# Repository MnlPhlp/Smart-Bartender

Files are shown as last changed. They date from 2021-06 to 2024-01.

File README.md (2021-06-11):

# Smart Bartender
This is a modified version of the [smart-bartender](https://youtu.be/2DopvpNF7J4) from Hacker Shack. It can be controlled via a webpage or an alexa skill.

For the building and electronics part watch the video or check the [hackster.io page](https://www.hackster.io/hackershack/smart-bartender-5c430e) of the original project.

## changes in the build
- switched the peristaltic pump for some cheaper and faster water pumps like [these](https://www.ebay.de/itm/131976810073?var=432870985005)
- using a [neopixel ring](https://www.adafruit.com/product/1463) for lighting
- using a [raspberry pi zero](https://www.raspberrypi.org/products/raspberry-pi-zero/) for control

## setup
To setup your pi you need to first install [circuitpython](https://learn.adafruit.com/circuitpython-on-raspberrypi-linux/installing-circuitpython-on-raspberry-pi). After that run:
```
curl https://raw.githubusercontent.com/MnlPhlp/Smart-Bartender/master/setup.sh | bash
```
This will clone the repository, create a venv and install necessary libraries. 
## start
To run the bartender `cd` into Smart-Bartender and start the program with:
```
sudo python bartender.py
```
> sudo is required for the neopixels to work

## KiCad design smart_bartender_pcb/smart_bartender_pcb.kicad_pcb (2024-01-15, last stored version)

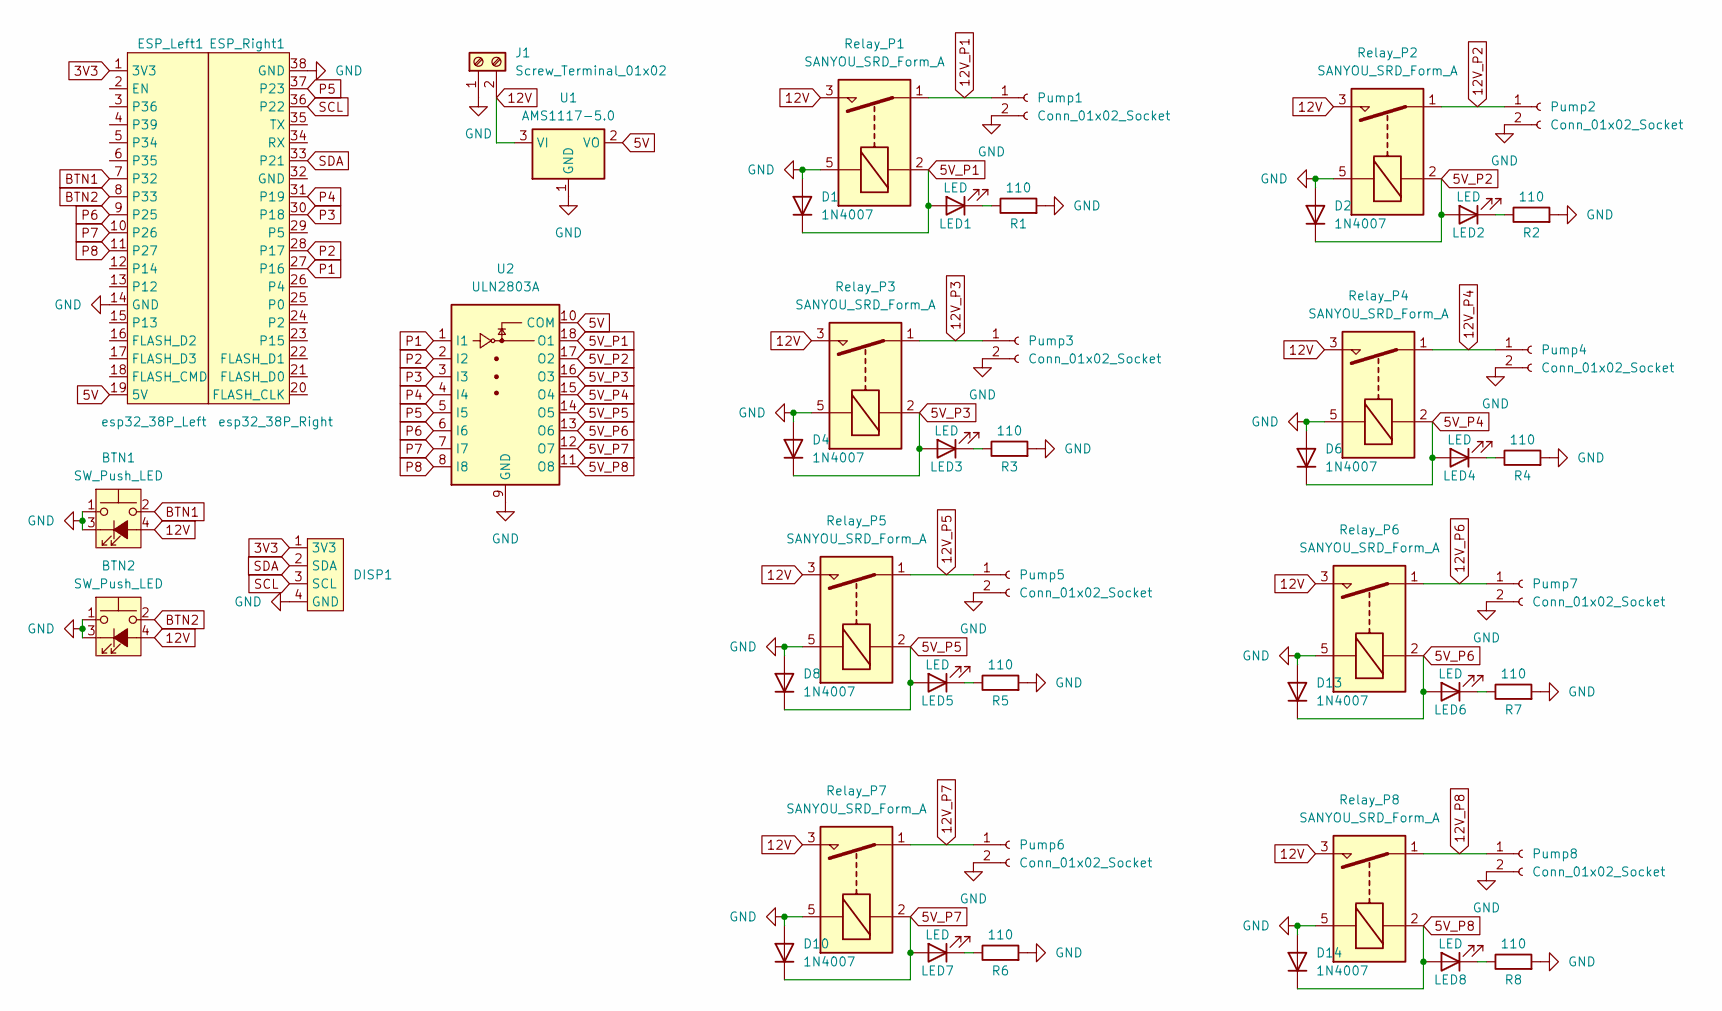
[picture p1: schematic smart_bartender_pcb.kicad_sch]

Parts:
BTN1, BTN2: SW_Push_LED; PinHeader_1x04_P2.54mm_Vertical; LCSC C5116483
D1, D2, D4, D6, D8, D10, D13, D14: 1N4007; D_SOD-123; LCSC C3018540
DISP1: PinSocket_1x04_P2.54mm_Horizontal; LCSC C5333413
ESP_Left1: esp32_38P_Left; esp32_38P_left; LCSC C319202
ESP_Right1: esp32_38P_Right; esp32_38P_right; LCSC C319202
J1: Screw_Terminal_01x02; TerminalBlock_Philmore_TB132_1x02_P5.00mm_Horizontal; LCSC C8385
LED1, LED2, LED3, LED4, LED5, LED6, LED7, LED8: LED; LED_0805_2012Metric; LCSC C2297
Pump1, Pump2, Pump3, Pump4, Pump5, Pump6, Pump7, Pump8: Conn_01x02_Socket; SolderWire-1.5sqmm_1x02_P6mm_D1.7mm_OD3mm_Relief
R1, R2, R3, R4, R5, R6, R7, R8: 110; R_0603_1608Metric; LCSC C22781
Relay_P1, Relay_P2, Relay_P3, Relay_P4, Relay_P5, Relay_P6, Relay_P7, Relay_P8: SANYOU_SRD_Form_A; Relay_SPST_SANYOU_SRD_Series_Form_A; LCSC C688862
U1: AMS1117-5.0; SOT-223-3_TabPin2
U2: ULN2803A; SOP-18_7.495x11.515mm_P1.27mm; LCSC C5252904

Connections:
3V3: DISP1.1 (3V3), ESP_Left1.1 (3V3)
5V: ESP_Left1.19 (5V), U1.2 (VO), U2.10 (COM)
5V_P1: D1.1 (K), LED1.2 (A), Relay_P1.2, U2.18 (O1)
5V_P2: D2.1 (K), LED2.2 (A), Relay_P2.2, U2.17 (O2)
5V_P3: D4.1 (K), LED3.2 (A), Relay_P3.2, U2.16 (O3)
5V_P4: D6.1 (K), LED4.2 (A), Relay_P4.2, U2.15 (O4)
5V_P5: D8.1 (K), LED5.2 (A), Relay_P5.2, U2.14 (O5)
5V_P6: D13.1 (K), LED6.2 (A), Relay_P6.2, U2.13 (O6)
5V_P7: D10.1 (K), LED7.2 (A), Relay_P7.2, U2.12 (O7)
5V_P8: D14.1 (K), LED8.2 (A), Relay_P8.2, U2.11 (O8)
12V: BTN1.4 (A), BTN2.4 (A), J1.2, Relay_P1.3, Relay_P2.3, Relay_P3.3, Relay_P4.3, Relay_P5.3, Relay_P6.3, Relay_P7.3, Relay_P8.3, U1.3 (VI)
12V_P1: Pump1.1, Relay_P1.1
12V_P2: Pump2.1, Relay_P2.1
12V_P3: Pump3.1, Relay_P3.1
12V_P4: Pump4.1, Relay_P4.1
12V_P5: Pump5.1, Relay_P5.1
12V_P6: Pump7.1, Relay_P6.1
12V_P7: Pump6.1, Relay_P7.1
12V_P8: Pump8.1, Relay_P8.1
BTN1: BTN1.2, ESP_Left1.7 (P32)
BTN2: BTN2.2, ESP_Left1.8 (P33)
GND: BTN1.1, BTN1.3 (K), BTN2.1, BTN2.3 (K), D1.2 (A), D2.2 (A), D4.2 (A), D6.2 (A), D8.2 (A), D10.2 (A), D13.2 (A), D14.2 (A), DISP1.4 (GND), ESP_Left1.14 (GND), ESP_Right1.38 (GND), J1.1, Pump1.2, Pump2.2, Pump3.2, Pump4.2, Pump5.2, Pump6.2, Pump7.2, Pump8.2, R1.2, R2.2, R3.2, R4.2, R5.2, R6.2, R7.2, R8.2, Relay_P1.5, Relay_P2.5, Relay_P3.5, Relay_P4.5, Relay_P5.5, Relay_P6.5, Relay_P7.5, Relay_P8.5, U1.1 (GND), U2.9 (GND)
unnamed: LED1.1 (K), R1.1
unnamed: LED2.1 (K), R2.1
unnamed: LED3.1 (K), R3.1
unnamed: LED4.1 (K), R4.1
unnamed: LED5.1 (K), R5.1
unnamed: LED6.1 (K), R7.1
unnamed: LED7.1 (K), R6.1
unnamed: LED8.1 (K), R8.1
P1: ESP_Right1.27 (P16), U2.1 (I1)
P2: ESP_Right1.28 (P17), U2.2 (I2)
P3: ESP_Right1.30 (P18), U2.3 (I3)
P4: ESP_Right1.31 (P19), U2.4 (I4)
P5: ESP_Right1.37 (P23), U2.5 (I5)
P6: ESP_Left1.9 (P25), U2.6 (I6)
P7: ESP_Left1.10 (P26), U2.7 (I7)
P8: ESP_Left1.11 (P27), U2.8 (I8)
SCL: DISP1.3 (SCL), ESP_Right1.36 (P22)
SDA: DISP1.2 (SDA), ESP_Right1.33 (P21)

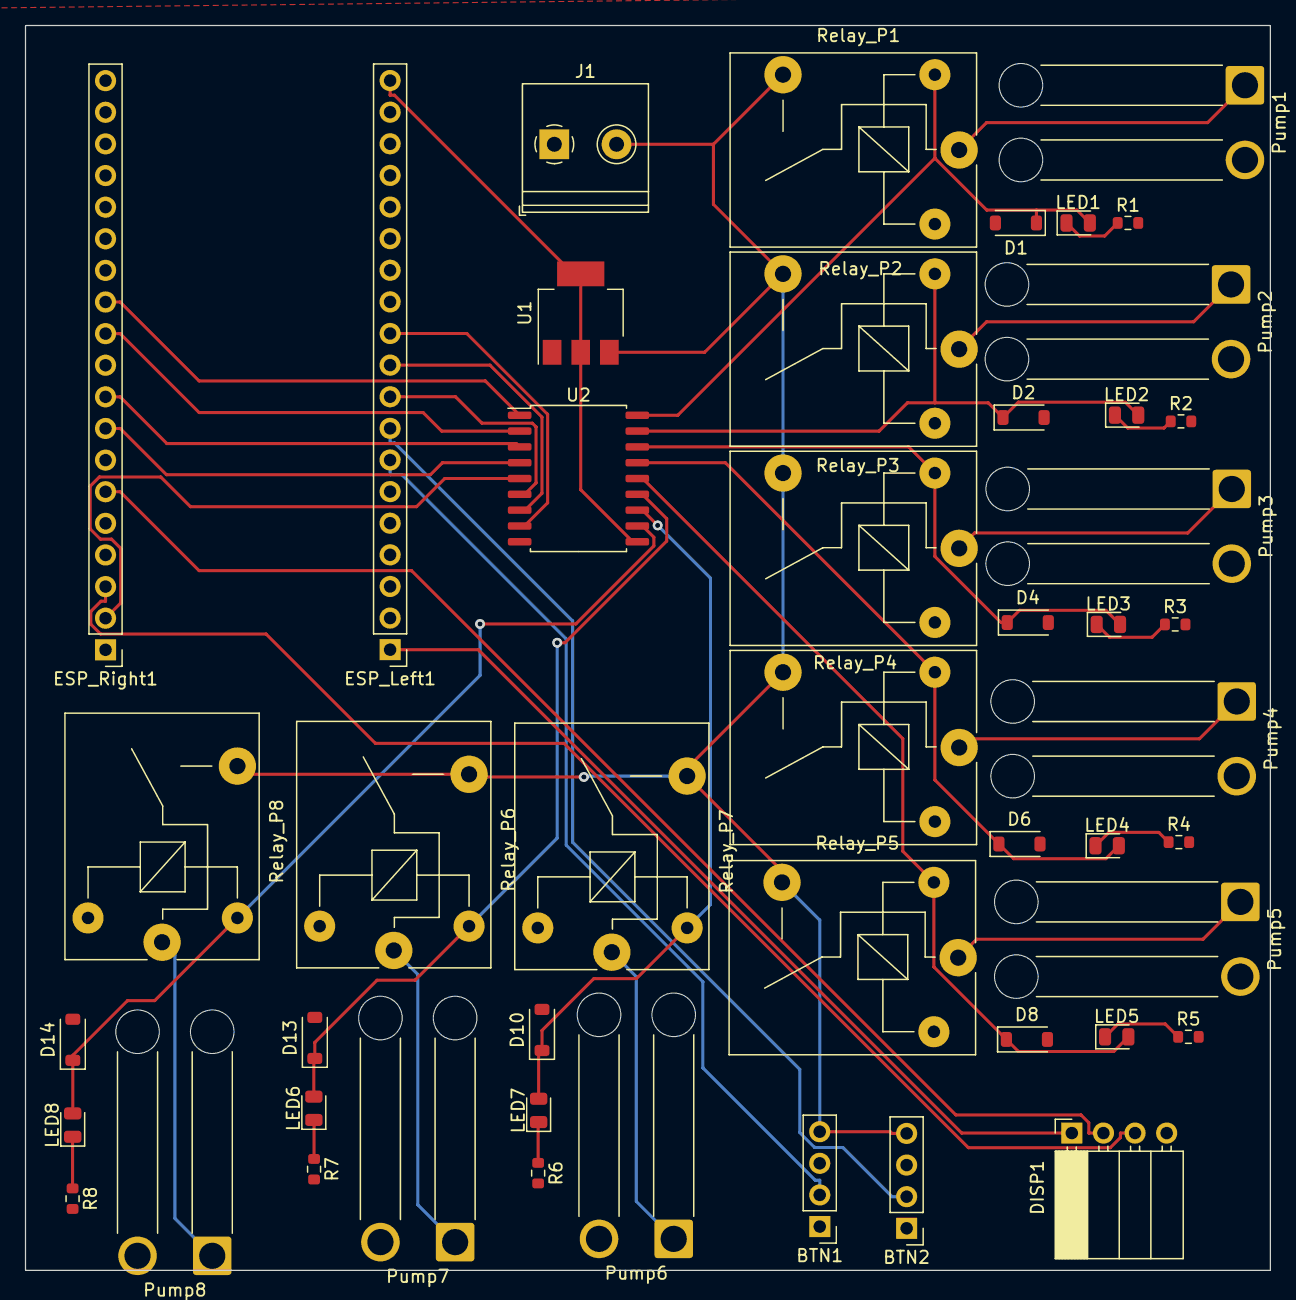
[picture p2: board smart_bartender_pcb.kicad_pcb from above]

Board: 2 copper layers, 100.0 x 100.0 mm, 48 parts (0 on the bottom side), 40 nets.

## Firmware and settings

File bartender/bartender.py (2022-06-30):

from helper.ledHelper import Led
from helper.displayHelper import Display, mockDisplay
from bartenderBase import BartenderBase
import time
import json
import threading
import board
import neopixel
import adafruit_ssd1306
from adafruit_debouncer import Debouncer
import digitalio
from adafruit_blinka.microcontroller.bcm283x.pin import Pin
import logging

SCREEN_WIDTH = 128
SCREEN_HEIGHT = 64

LEFT_BTN_PIN = board.D14
LEFT_PIN_BOUNCE = 500

RIGHT_BTN_PIN = board.D15
RIGHT_PIN_BOUNCE = 500

NUMBER_NEOPIXELS = 12
NEOPIXEL_PIN = board.D18
NEOPIXEL_BRIGHTNESS = 0.5
BASE_COLOR = (50, 0, 0)


class Bartender(BartenderBase):
    leds: Led
    server: BartenderServer
    stats: dict
    running: bool
    stopEvent: threading.Event

    def __init__(self,server, username, password):
        super(Bartender, self).__init__(server,username,password)

        # setup led strip:
        self.leds = Led(neopixel.NeoPixel(
            NEOPIXEL_PIN, NUMBER_NEOPIXELS, brightness=NEOPIXEL_BRIGHTNESS), BASE_COLOR)
        self.leds.clear()
        self.leds.powerUpSequence()
        self.leds.startCycle()

        # setup buttons
        pin1 = digitalio.DigitalInOut(LEFT_BTN_PIN)
        pin1.direction = digitalio.Direction.INPUT
        pin1.pull = digitalio.Pull.UP
        self.btn1 = Debouncer(pin1, interval=0.2)

        pin2 = digitalio.DigitalInOut(RIGHT_BTN_PIN)
        pin2.direction = digitalio.Direction.INPUT
        pin2.pull = digitalio.Pull.UP
        self.btn2 = Debouncer(pin2, interval=0.2)

        # configure screen
        try:
            dsp = adafruit_ssd1306.SSD1306_I2C(
                SCREEN_WIDTH, SCREEN_HEIGHT, board.I2C(), addr=0x3C)
        except:
            logging.warn("no display found. Using mock display")
            dsp = mockDisplay()
        self.display = Display(dsp)
        # Clear display.
        self.display.setup()
        self.display.show()

        # load the pump configuration from file
        self.pump_configuration = Bartender.readPumpConfiguration()

        self.leds.stopCycle()
        self.leds.shutdownSequence()
        logging.info("Done initializing")

    @staticmethod
    def readPumpConfiguration():
        config = json.load(open('config/pump_config.json'))
        for pump in config.keys():
            pinId = config[pump]["pin"]
            pin = digitalio.DigitalInOut(Pin(pinId))
            pin.direction = digitalio.Direction.OUTPUT
            pin.value = True
            config[pump]["pin"] = pin
        return config

    def writePumpConfiguration(self):
        jsonData = {}
        # create a deep copy to change the pins from objects back to ints
        for pump in self.pump_configuration.keys():
            jsonData[pump] = {
                "value": self.pump_configuration[pump]["value"],
                "name": self.pump_configuration[pump]["name"],
                "pin": self.pump_configuration[pump]["pin"]._pin.id,
                "rate": self.pump_configuration[pump]["rate"]

            }
        with open("config/pump_config.json", "w") as jsonFile:
            json.dump(jsonData, jsonFile)

    def clean(self):
        waitTime = 20
        pumpThreads = []

        # cancel any button presses while the drink is being made
        self.running = True

        for pump in self.pump_configuration.keys():
            pump_t = threading.Thread(target=self.pour, args=(
                self.pump_configuration[pump]["pin"], waitTime))
            pumpThreads.append(pump_t)

        # start the pump threads
        for thread in pumpThreads:
            thread.start()

        # start the progress bar
        self.progressBar(waitTime)

        # wait for threads to finish
        for thread in pumpThreads:
            thread.join()

        # show the main menu
        self.menuContext.showMenu()

        # sleep for a couple seconds to make sure the interrupts don't get triggered
        time.sleep(2)

        # reenable interrupts
        self.running = False

    def displayMenuItem(self, menuItem):
        logging.info(f"current menu: {menuItem.name}")
        self.display.clear()
        self.display.displayText(menuItem.name)
        self.display.show()

    def pour(self, pin, waitTime):
        pin.value = False
        logging.info(f"pump on pin {pin._pin} started")
        self.stopEvent.wait(waitTime)
        pin.value = True
        logging.info(f"pump on pin {pin._pin} stoped")

    def progressBar(self, waitTime):
        stepTime = 0.05
        start = time.time()
        percent = 0
        while percent < 100 and not self.stopEvent.is_set():
            loopStart = time.time()
            # update the progress bar
            self.display.drawProgressBar(percent)
            self.display.show()
            # wait the remaining time to limit refreshes
            loopElapsed = time.time()-loopStart
            if loopElapsed < stepTime:
                time.sleep(stepTime-loopElapsed)
            # update the percentage
            percent = ((time.time()-start)/waitTime*100)

        self.display.drawProgressBar(100)

    def makeDrink(self, drink, ingredients):
        # cancel any button presses while the drink is being made
        self.running = True
        self.addStats(drink, ingredients)

        # display the drink in the making
        self.display.clear()
        self.display.displayText(drink)

        # launch a thread to control lighting
        self.leds.startCycle()

        # Parse the drink ingredients and spawn threads for pumps
        maxTime = 0
        pumpThreads = []
        pumps = self.pump_configuration
        for pump in [pumps[key] for key in pumps if pumps[key]["value"] in ingredients]:
            waitTime = ingredients[pump["value"]]/pump["rate"]
            if (waitTime > maxTime):
                maxTime = waitTime
            pump_t = threading.Thread(
                target=self.pour, args=(pump["pin"], waitTime))
            pumpThreads.append(pump_t)

        # start the pump threads
        for thread in pumpThreads:
            thread.start()

        # start the progress bar
        self.progressBar(maxTime)

        # wait for threads to finish
        for thread in pumpThreads:
            thread.join()

        # show the main menu
        self.menuContext.showMenu()

        # stop the light thread
        self.leds.stopCycle()
        self.leds.shutdownSequence()

        # reenable interrupts
        self.running = False

    def handleInput(self):
        self.btn1.update()
        self.btn2.update()
        if self.btn1.fell:
            self.left_btn()
        if self.btn2.fell:
            self.right_btn()

    def stop(self):
        logging.info("stopping current drink")
        self.stopEvent.set()
        # wait for everything to finish
        while self.running:
            time.sleep(0.5)
        self.stopEvent.clear()
        logging.info("drink is stoped")
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

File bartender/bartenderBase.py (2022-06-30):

import string
from menu import MenuItem, Menu, Back, MenuContext, MenuDelegate
import json
from datetime import datetime
import threading
import logging
from time import sleep
from config.drinks import drink_list as drink_list_import, drink_options as drink_options_import
import requests


class BartenderBase(MenuDelegate):
    stats: dict
    running: bool
    stopEvent: threading.Event
    server: string
    username: string
    password: string

    def __init__(self,server, username, password):
        self.running = False
        self.stopEvent = threading.Event()
        self.server = server
        self.username = username
        self.password = password

        self.stats = self.loadStats()

    def addStats(self, drink, ingredients):
        time = datetime.now().strftime("%d.%m.%y-%H:%M")
        # create entries if they don't exist
        if not time in self.stats:
            self.stats[time] = {}
        stats = self.stats[time]
        total = self.stats["total"]
        if not drink in stats:
            stats[drink] = 0
        if not drink in total:
            total[drink] = 0
        # add the volume to the entries
        total[drink] += 1
        stats[drink] = total[drink]
        self.saveStats()

    def loadStats(self):
        try:
            with open("stats.json", "rt") as f:
                return json.load(f)
        except FileNotFoundError:
            return {"total": {}}

    def saveStats(self):
        with open("stats.json", "wt") as f:
            return json.dump(self.stats, f)

    def buildMenu(self, drink_list, drink_options):
        # create a new main menu
        m = Menu("Main Menu")

        # add drink options
        drink_opts = []
        for d in drink_list:
            drink_opts.append(MenuItem('drink', d["name"], {
                              "ingredients": d["ingredients"]}))

        configuration_menu = Menu("Configure")

        # add pump configuration options
        pump_opts = []
        for p in sorted(self.pump_configuration.keys()):
            config = Menu(self.pump_configuration[p]["name"])
            # add fluid options for each pump
            for opt in drink_options:
                # star the selected option
                selected = "*" if opt == self.pump_configuration[p]["value"] else ""
                config.addOption(MenuItem('pump_selection', opt, {
                                 "key": p, "value": opt, "name": opt}))
            # add a back button so the user can return without modifying
            config.addOption(Back("Back"))
            config.setParent(configuration_menu)
            pump_opts.append(config)

        # add pump menus to the configuration menu
        configuration_menu.addOptions(pump_opts)
        # add a back button to the configuration menu
        configuration_menu.addOption(Back("Back"))
        # adds an option that cleans all pumps to the configuration menu
        configuration_menu.addOption(MenuItem('clean', 'Clean'))
        # add reload drinks option to reload drinks from the server
        configuration_menu.addOption(MenuItem("reload_drinks", "Reload drinks"))
        configuration_menu.setParent(m)

        m.addOptions(drink_opts)
        m.addOption(configuration_menu)
        # create a menu context
        self.menuContext = MenuContext(m, self)

    def filterDrinks(self, menu):
        """
        Removes any drinks that can't be handled by the pump configuration
        """
        for i in menu.options:
            if (i.type == "drink"):
                i.visible = False
                ingredients = i.attributes["ingredients"]
                presentIng = 0
                for ing in ingredients.keys():
                    for p in self.pump_configuration.keys():
                        if (ing == self.pump_configuration[p]["value"]):
                            presentIng += 1
                if (presentIng == len(ingredients.keys())):
                    i.visible = True
            elif (i.type == "menu"):
                self.filterDrinks(i)

    def selectConfigurations(self, menu):
        """
        Adds a selection star to the pump configuration option
        """
        for i in menu.options:
            if (i.type == "pump_selection"):
                key = i.attributes["key"]
                if (self.pump_configuration[key]["value"] == i.attributes["value"]):
                    i.name = "%s %s" % (i.attributes["name"], "*")
                else:
                    i.name = i.attributes["name"]
            elif (i.type == "menu"):
                self.selectConfigurations(i)

    def prepareForRender(self, menu):
        self.filterDrinks(menu)
        self.selectConfigurations(menu)
        return True

    def menuItemClicked(self, menuItem):
        if (menuItem.type == "drink"):
            def func(): return self.makeDrink(
                menuItem.name, menuItem.attributes["ingredients"])
            t = threading.Thread(target=func)
            t.start()
            return True
        elif(menuItem.type == "pump_selection"):
            self.pump_configuration[menuItem.attributes["key"]
                                    ]["value"] = menuItem.attributes["value"]
            self.writePumpConfiguration()
            return True
        elif(menuItem.type == "clean"):
            self.clean()
            return True
        elif(menuItem.type == "reload_drinks"):
            drink_list, drink_options = self.loadDrinks()
            self.buildMenu(drink_list, drink_options)
        return False

    def stop(self):
        if not self.running:
            return
        logging.info("stopping current drink")
        self.stopEvent.set()
        # wait for everything to finish
        while self.running:
            sleep(0.5)
        self.stopEvent.clear()
        logging.info("drink is stoped")

    def left_btn(self):
        logging.info("left button pressed")
        if not self.running:
            logging.info("menu advance")
            self.menuContext.advance()

    def right_btn(self):
        logging.info("right button pressed")
        if not self.running:
            logging.info("menu select")
            self.menuContext.select()
        else:
            logging.info("stop")
            self.stop()
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

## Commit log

2021-05-21 tried to fix for python 3
    [bartender.py]
2021-05-21 fixed neopixel pin
2021-05-26 switched from GPIO to digitalio library
2021-05-26 implemented stopping with threading event
2021-05-27 fixed button and stop handling
    [bartender.py]
2021-05-27 fixed pump config writing/reading
    [bartender.py]
2021-05-28 added stop button when making drink
2024-01-15 started pcb
    [smart_bartender_pcb.kicad_pcb, smart_bartender_pcb.kicad_sch]
2024-01-15 started pcb layout
    [smart_bartender_pcb.kicad_pcb, smart_bartender_pcb.kicad_sch]
2024-01-15 updated pcb
    [smart_bartender_pcb.kicad_pcb]
2024-01-16 move new stuff to separate repo
    [smart_bartender_pcb.kicad_pcb, smart_bartender_pcb.kicad_sch]
